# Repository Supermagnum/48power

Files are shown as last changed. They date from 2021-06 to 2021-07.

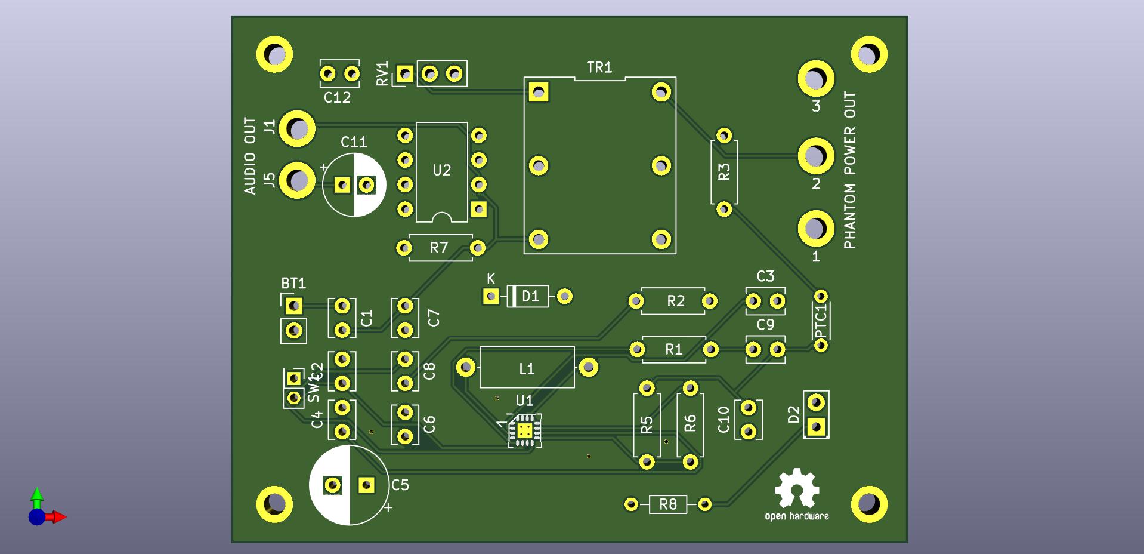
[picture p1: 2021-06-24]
front.jpg

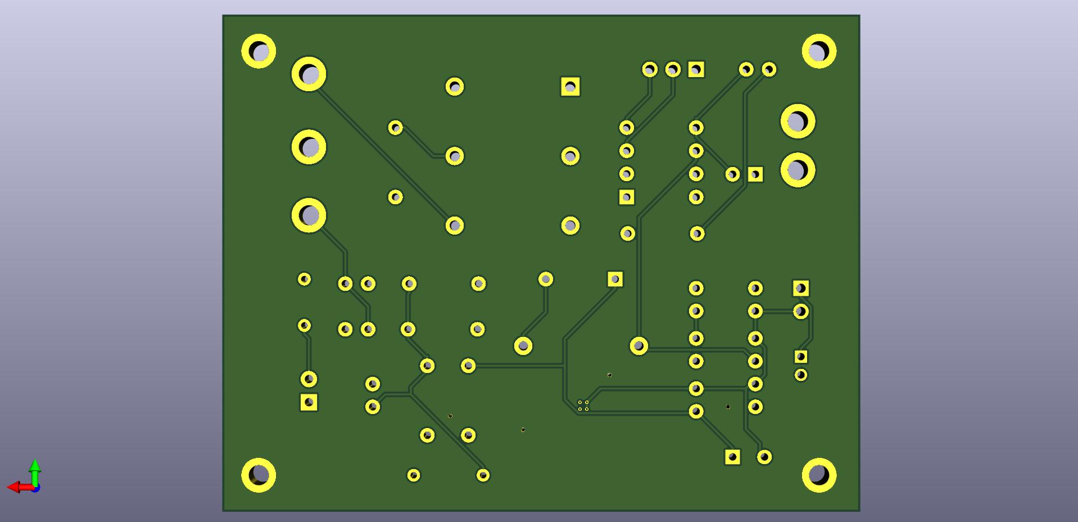
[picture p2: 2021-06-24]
back.jpg

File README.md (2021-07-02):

# 48power
A small PCB that supplies +48 volt phantom power to a balanced audio system. It also has audio out to mono headphone.
It uses a LM51571QRTERQ1 to boost the voltage from a 9V battery to +48 V and a Hammond Manufacturing 108F Audio transformer.

Datasheet for the transformer:
https://github.com/Supermagnum/48power/blob/main/108F(1).pdf

Datasheet for LM51571QRTERQ1 in WQFN (16) package :
https://github.com/Supermagnum/48power/blob/main/lm51571-q1.pdf

Component selection according to Texas Instruments calculator:
https://raw.githubusercontent.com/Supermagnum/48power/main/WBSchematicXLM5157QRTERQ1.svg

Now also with a small mono amplifier, with adjustable volume ( potentiometer ).

LM386 datasheet:
https://github.com/Supermagnum/48power/blob/main/lm386(2).pdf

Please use metal film resistors, 1% tolerance or better.
High quality capacitors, audio grade ceramic X7R or better.

All component values is on the pdf file:
https://github.com/Supermagnum/48power/blob/main/supply.pdf
There is only one SMD component.

PCB board dimensions:
https://raw.githubusercontent.com/Supermagnum/48power/main/dimentions.png

Aisler PCB:
https://aisler.net/p/QQVLMIWH

The PCB board is to be mounted inside a metal box, on metal standoffs.
Ø2mm bolts with nuts can be used.
The components on the PCB must not touch the metal box.
The XLR cable shield must be connected to the metal box.
No of the internal leads should at any time be connected to the metal box.
Use a Ø4mm cable that has shield and 3 conductors.
A 3 pin XLR connector is wired up like this: https://github.com/Supermagnum/piezo-balanced/blob/main/XLR%2BConnector%2BPinout%2BDiagram%2BRear%2BPin%2B2%2BHot%2Bv2%2Bgreen__01.jpg 

NOTE:  
The XLR 3 pin plug has a solder lug for the shield for a reason.
It is my opinion that a shielded cable with 3 conductors inside is the best.
Suggested cable: Digi-Key Part Number:30-01225-5-ND

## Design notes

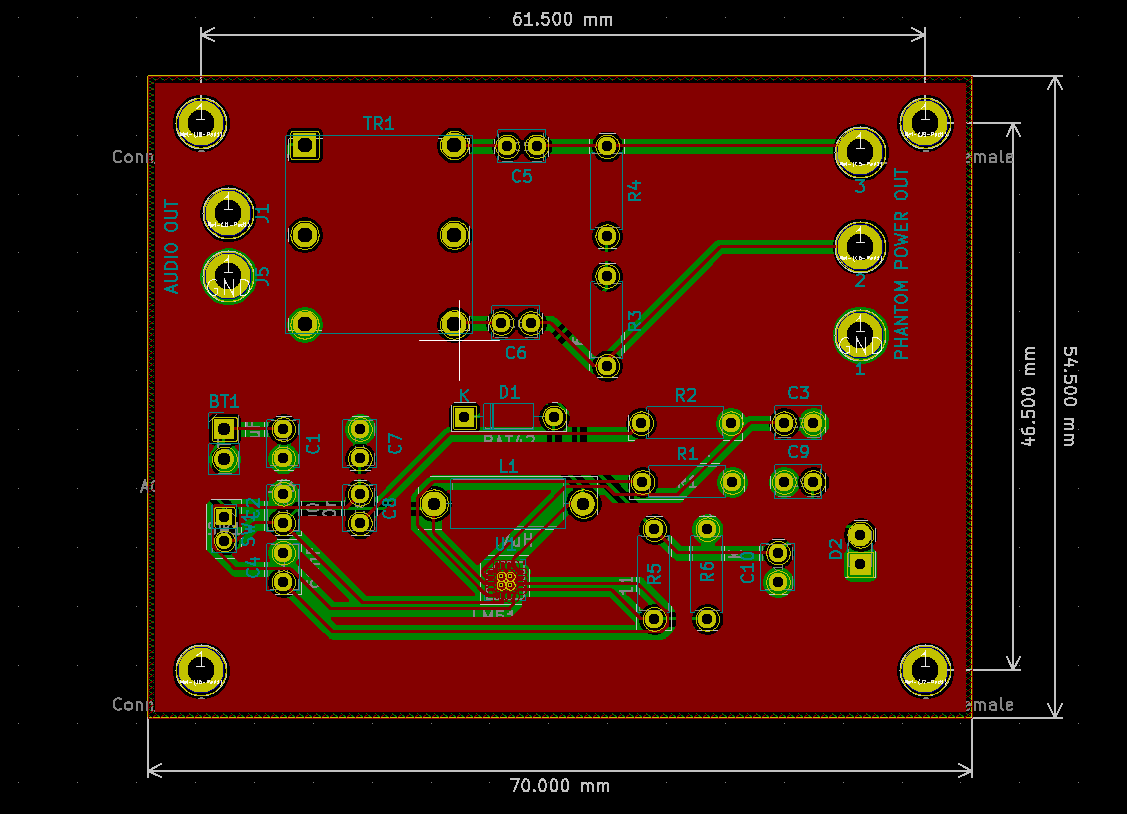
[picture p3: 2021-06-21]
dimentions.png

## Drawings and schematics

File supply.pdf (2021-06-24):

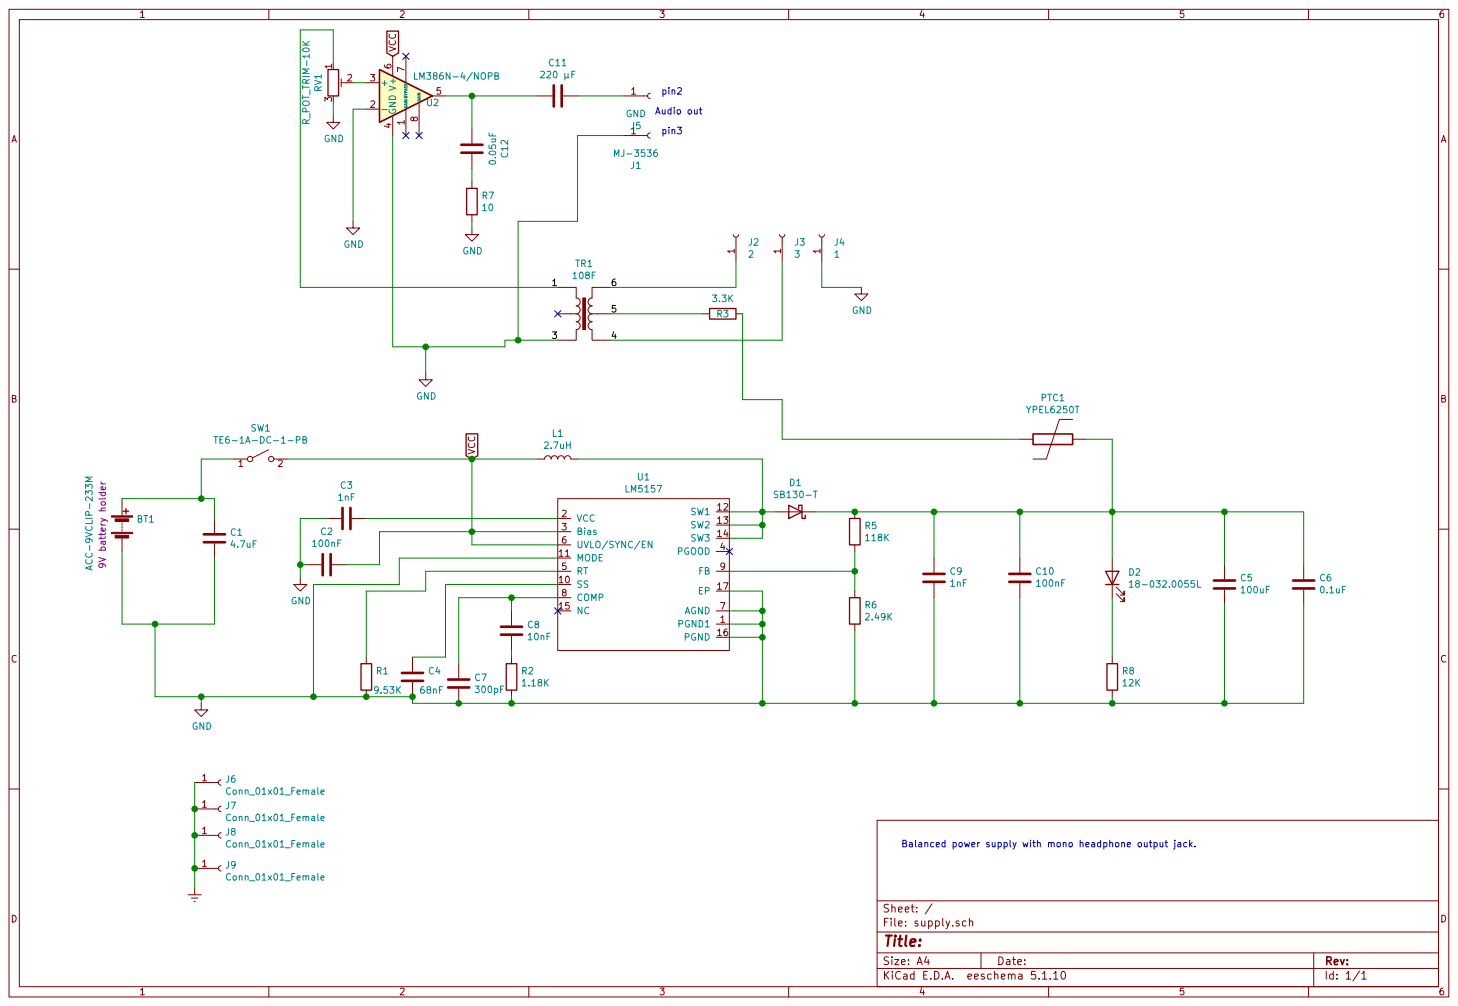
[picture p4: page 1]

Balanced power supply with mono headphone output jack.

File: supply.sch Sheet: /
Id: 1/1 Title:

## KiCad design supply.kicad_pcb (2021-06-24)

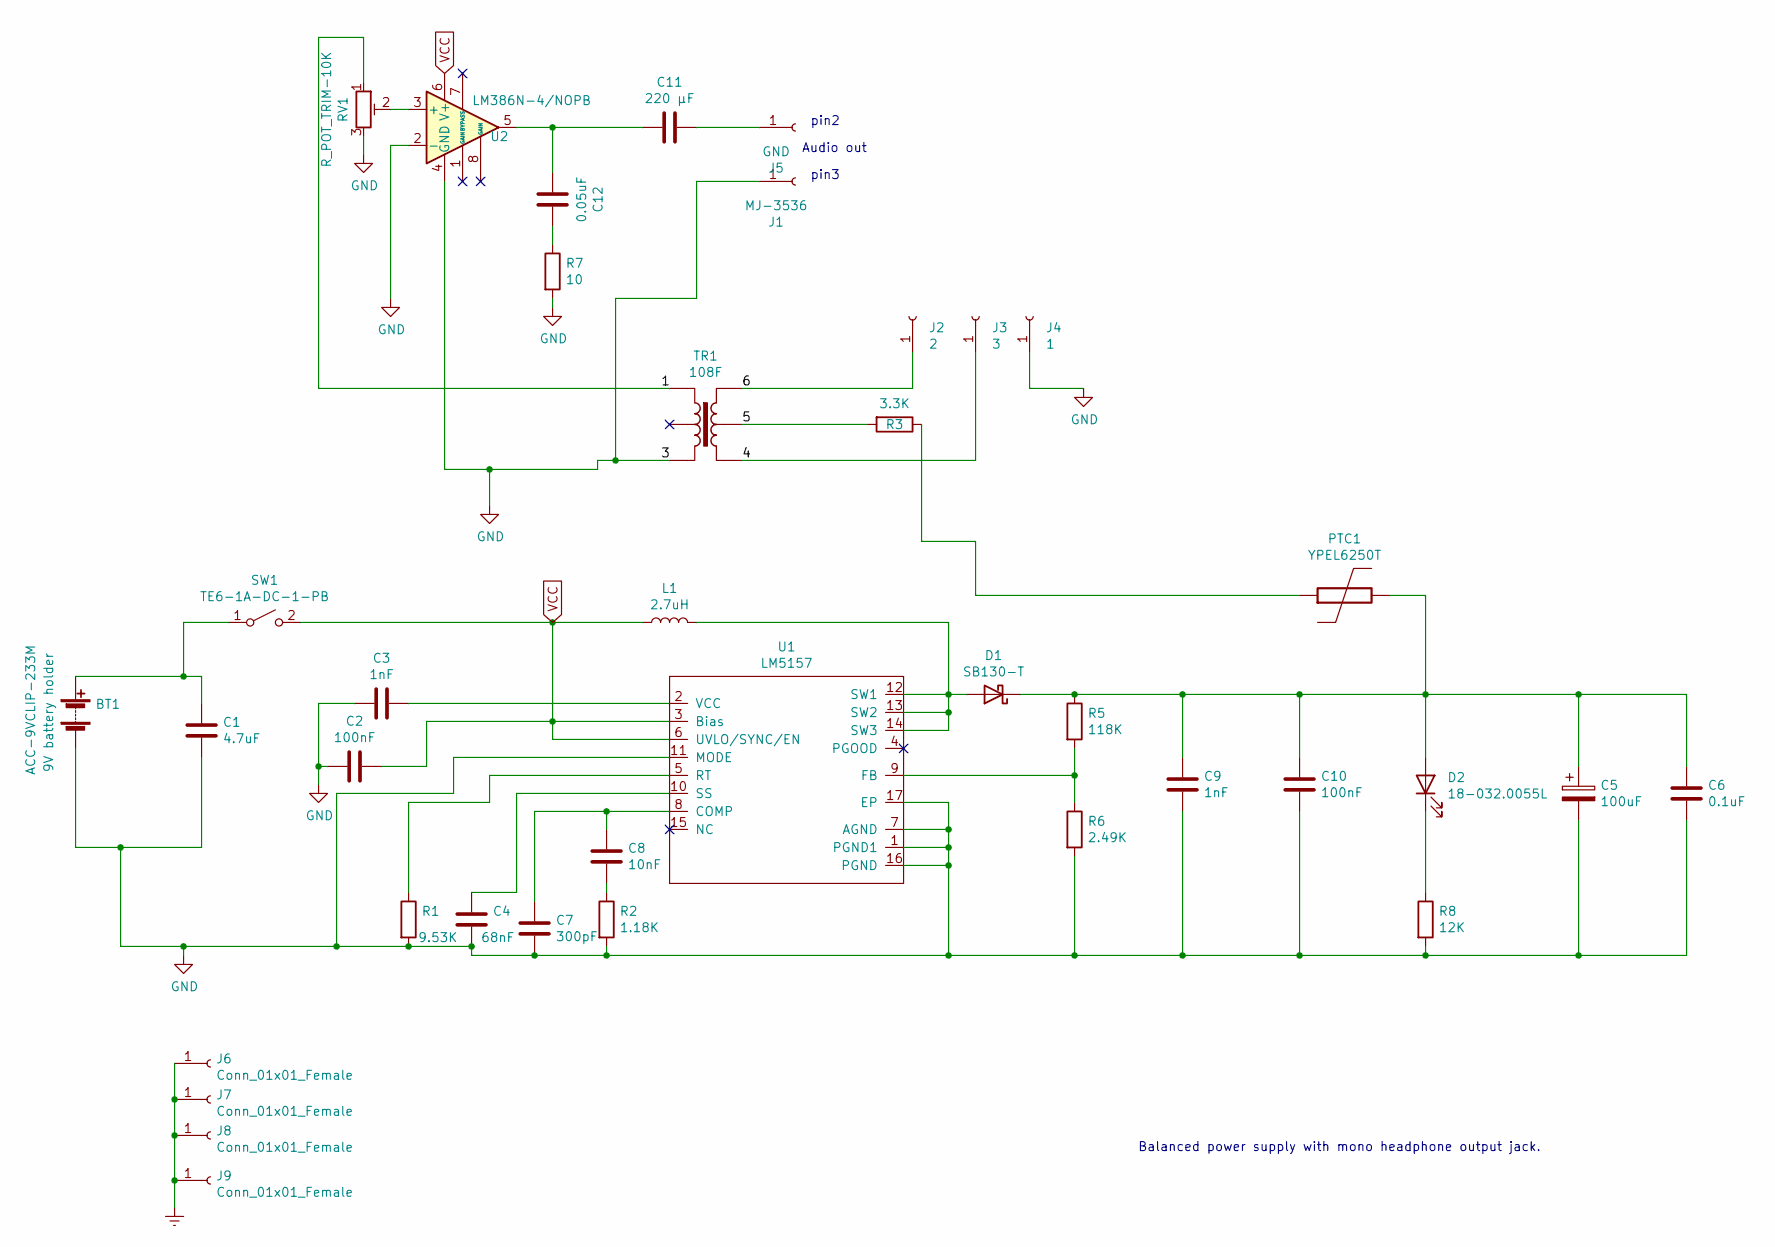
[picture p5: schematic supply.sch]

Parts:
BT1: ACC-9VCLIP-233M; PinHeader_1x02_P2.54mm_Vertical
C1: 4.7uF; C_Disc_D3.8mm_W2.6mm_P2.50mm
C2, C10: 100nF; C_Disc_D3.8mm_W2.6mm_P2.50mm
C3, C9: 1nF; C_Disc_D3.8mm_W2.6mm_P2.50mm
C4: 68nF; C_Disc_D3.8mm_W2.6mm_P2.50mm
C5: 100uF; CP_Radial_D8.0mm_P3.50mm
C6: 0.1uF; C_Disc_D3.8mm_W2.6mm_P2.50mm
C7: 300pF; C_Disc_D3.8mm_W2.6mm_P2.50mm
C8: 10nF; C_Disc_D3.8mm_W2.6mm_P2.50mm
C11: 220 µF; CP_Radial_D6.3mm_P2.50mm
C12: 0.05uF; C_Disc_D3.8mm_W2.6mm_P2.50mm
D1: SB130-T; D_DO-35_SOD27_P7.62mm_Horizontal
D2: 18-032.0055L; LED_D2.0mm_W4.8mm_H2.5mm_FlatTop
J1: MJ-3536; MountingHole_2.2mm_M2_DIN965_Pad
J2: 2; MountingHole_2.2mm_M2_DIN965_Pad
J3: 3; MountingHole_2.2mm_M2_DIN965_Pad
J4: 1; MountingHole_2.2mm_M2_DIN965_Pad
J5: GND; MountingHole_2.2mm_M2_DIN965_Pad
J6, J7, J8, J9: Conn_01x01_Female; MountingHole_2.2mm_M2_DIN965_Pad
L1: 2.7uH; L_Axial_L9.5mm_D4.0mm_P12.70mm_Horizontal_Fastron_SMCC
PTC1: YPEL6250T; R_Axial_DIN0204_L3.6mm_D1.6mm_P5.08mm_Horizontal
R1: 9.53K; R_Axial_DIN0207_L6.3mm_D2.5mm_P7.62mm_Horizontal
R2: 1.18K; R_Axial_DIN0207_L6.3mm_D2.5mm_P7.62mm_Horizontal
R3: 3.3K; R_Axial_DIN0207_L6.3mm_D2.5mm_P7.62mm_Horizontal
R5: 118K; R_Axial_DIN0207_L6.3mm_D2.5mm_P7.62mm_Horizontal
R6: 2.49K; R_Axial_DIN0207_L6.3mm_D2.5mm_P7.62mm_Horizontal
R7: 10; R_Axial_DIN0207_L6.3mm_D2.5mm_P7.62mm_Horizontal
R8: 12K; R_Axial_DIN0204_L3.6mm_D1.6mm_P7.62mm_Horizontal
RV1: R_POT_TRIM-10K; PinHeader_1x03_P2.54mm_Vertical
SW1: TE6-1A-DC-1-PB; PinHeader_2x01_P2.00mm_Vertical
TR1: 108F
U1: LM5157; WQFN-16_EP_3.15x3.15_Pitch0.5mm
U2: LM386N-4/NOPB; DIP-8_W7.62mm

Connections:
/1: RV1.1, TR1.1
/4: J3.1, TR1.4
/5: R3.2, TR1.5
/6: J2.1, TR1.6
Earth: J6.1, J7.1, J8.1, J9.1
GND: BT1.2 (-), C1.2, C2.2, C3.2, C4.2, C5.2, C6.1, C7.2, C9.1, C10.1, J1.1, J4.1, R1.2, R2.2, R6.2, R7.2, R8.2, RV1.3, TR1.3, U1.1 (PGND1), U1.7 (AGND), U1.11 (MODE), U1.16 (PGND), U1.17 (EP), U2.2 (-), U2.4 (GND)
unnamed: BT1.1 (+), C1.1, SW1.1 (A)
unnamed: C3.1, U1.2 (VCC)
unnamed: C4.1, U1.10 (SS)
unnamed: C7.1, C8.1, U1.8 (COMP)
unnamed: C8.2, R2.1
unnamed: C5.1, C6.2, C9.2, C10.2, D1.1 (K), D2.2 (A), PTC1.2, R5.1
unnamed: C11.1, J5.1
unnamed: C11.2, C12.2, U2.5
unnamed: C12.1, R7.1
unnamed: D1.2 (A), L1.2, U1.12 (SW1), U1.13 (SW2), U1.14 (SW3)
unnamed: D2.1 (K), R8.1
unnamed: PTC1.1, R3.1
unnamed: R1.1, U1.5 (RT)
unnamed: R5.2, R6.1, U1.9 (FB)
unnamed: RV1.2, U2.3 (+)
VCC: C2.1, L1.1, SW1.2 (B), U1.3 (Bias), U1.6 (UVLO/SYNC/EN), U2.6 (V+)

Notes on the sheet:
Balanced power supply with mono headphone output jack.
Audio out
pin2
pin3

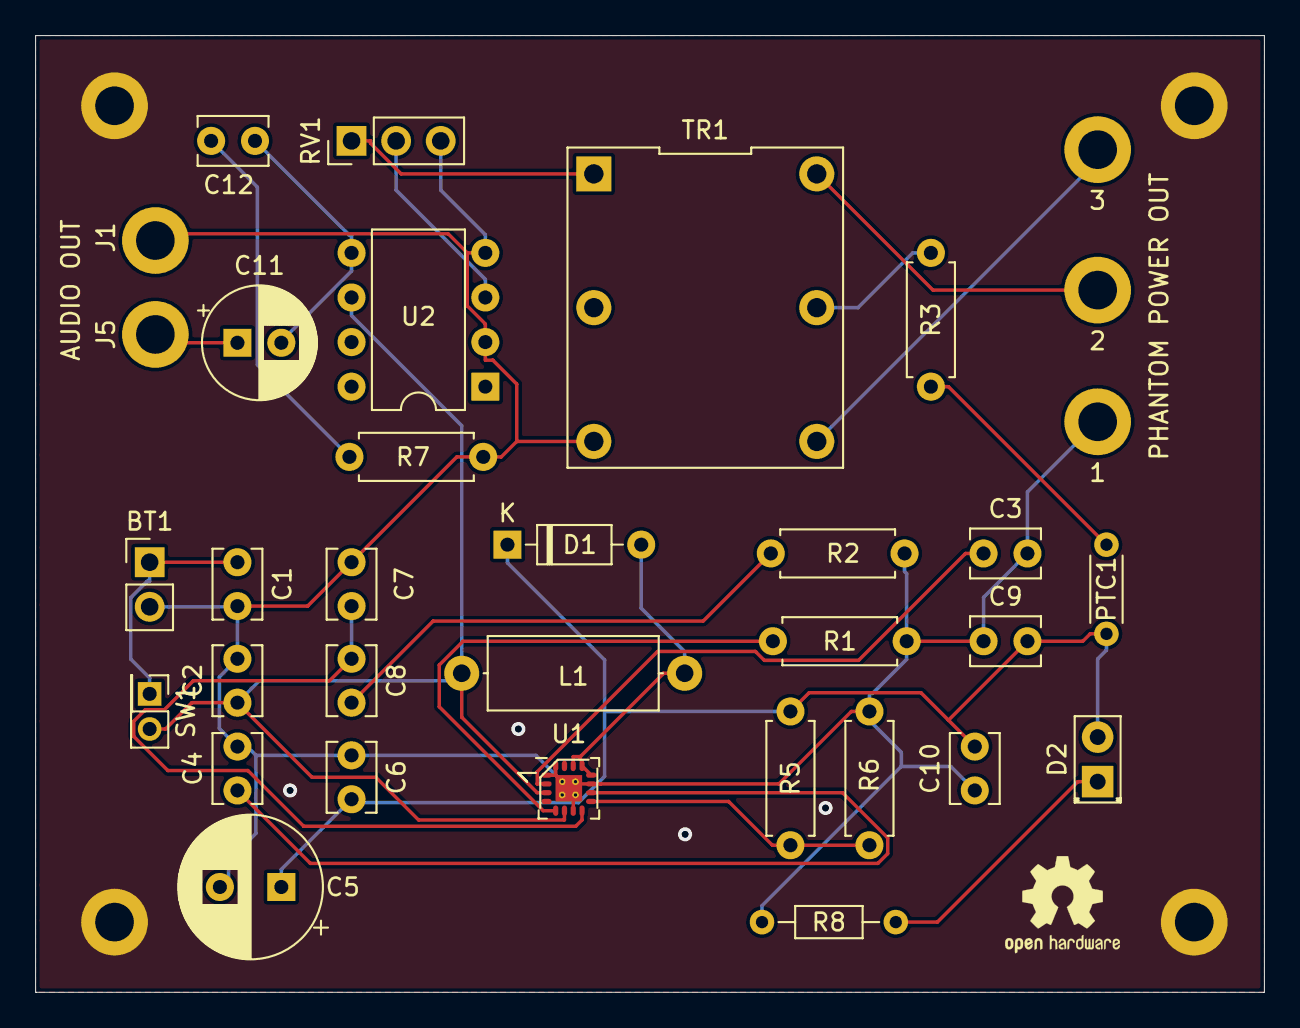
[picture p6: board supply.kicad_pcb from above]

Board: 2 copper layers, 70.0 x 54.5 mm, 38 parts (0 on the bottom side), 22 nets.

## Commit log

2021-06-21 Add files via upload
    updated
    [supply-B_Cu.gbr, supply-B_Mask.gbr, supply-B_Paste.gbr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]
2021-06-21 Add files via upload
    Updated files.
    [supply-B_Cu.gbr, supply-B_Mask.gbr, supply-B_Paste.gbr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]
2021-06-23 Add files via upload
    update, added correct diode and PCT fuse.
    [supply-B_Cu.gbr, supply-B_Mask.gbr, supply-B_Paste.gbr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]
2021-06-23 Add files via upload
    update due to component change.
    [supply-B_Cu.gbr, supply-B_Mask.gbr, supply-B_Paste.gbr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]
